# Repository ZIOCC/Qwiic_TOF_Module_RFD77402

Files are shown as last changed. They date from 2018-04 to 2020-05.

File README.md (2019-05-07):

# Qwiic TOF Module (RFD77402)

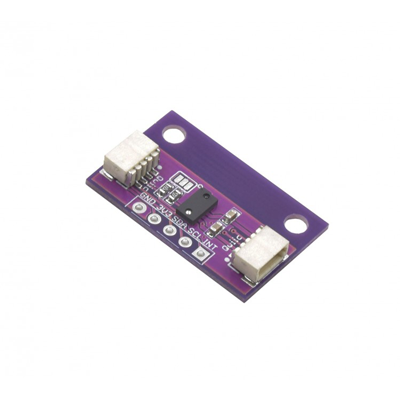
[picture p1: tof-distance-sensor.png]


> This product can be available for purchase [here](https://www.smart-prototyping.com/Zio-TOF-Distance-Sensor-RFD77402.html).

#### Description

In the words of a team member, “kind of dope AF”, this Zio ToF Distance Sensor measures distance faster than the Flash can cover it. If you don’t believe us, you can ask him.

This little board features an RFD77402 time-of-flight rangefinding IC, measuring up to 2m in distance. The sensor uses a vertical-cavity surface-emitting laser (or VCSEL), and measures the time it takes for photons to make the round-trip to the laser’s target, and back to the built-in detector. The laser emitter is class 1, therefore safe for most all applications.

We’ve outfitted the board with mounting holes on wing tabs that can be snapped off to create an even smaller board if you don’t need them. Two Qwiic connectors occupy either side of the breakout board so you can quickly and easily daisy-chain it with other modules. It also includes a standard-pitch header for use with projects that aren’t Qwiic-based.

Apply this sensor in a wide-range of applications such as in robotics for obstacle detection and avoidance, 1D gesture recognition, hand detection, volume or height control, relative position of linear actuators, or for user proximity detection for IoT devices.

Check out this Brick Breaker game that we hacked together using a similar sensor.

#### Specification

* Light Source: VCSEL / 850 nm
* Field of Illumination: 29-degree @ 1/e2
* Field of View: 55-degree @ 1/e2
* Measurement Range: 100-2000mm
* Refresh Rate: 10Hz
* Precision: ±10%
* Laser Eye Safety: Class 1
* Current Consumption: 7-15mA
* IC: RFD77402
* I2C address: 0x4C
* Dimensions: 16.5x 26.3mm (with mounting bar). 26.3x10.5mm (without mounting bar)
* Weight: 1.2g

#### Links

* [RFD77402 Datasheet](https://www.smart-prototyping.com/image/data/NOA-RnD/101891%20TOF/RFD77402DatasheetRev1-8.pdf)
* [SparkFun RFD77402  Library](https://github.com/sparkfun/SparkFun_RFD77402_Arduino_Library)
* [Eagle files](https://github.com/ZIOCC/Qwiic_TOF_Module_RFD77402)

> ###### About Zio
> Zio is a new line of open sourced, compact, and grid layout boards, fully integrated for Arduino and Qwiic ecosystem. Designed ideally for wearables, robotics, small-space limitations or other on the go projects. Check out other awesome Zio products [here](https://www.smart-prototyping.com/Zio).

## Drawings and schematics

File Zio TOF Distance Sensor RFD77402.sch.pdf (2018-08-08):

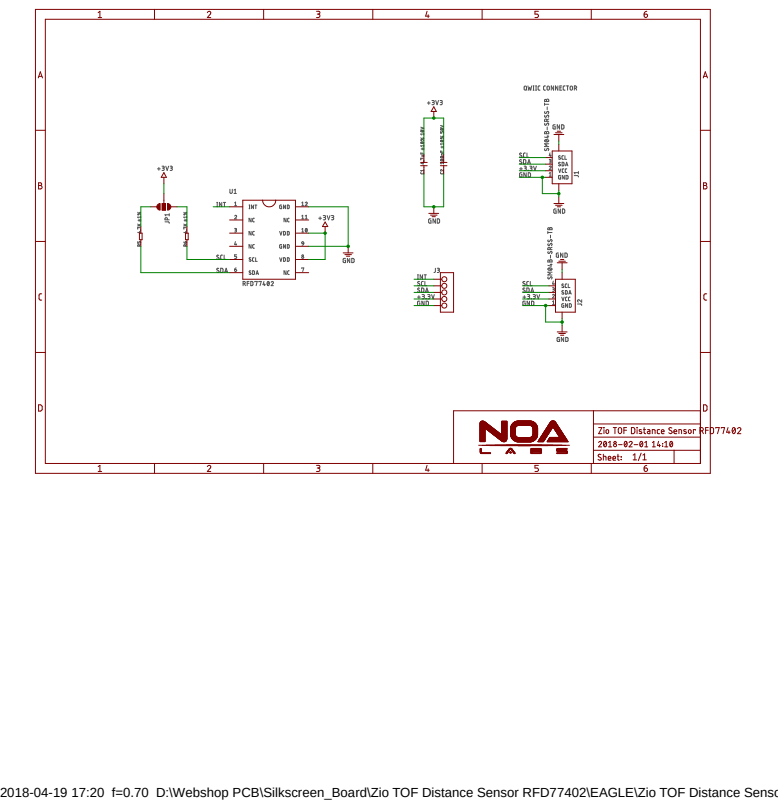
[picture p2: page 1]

2018-04-19 17:20 f=0.70 D:\Webshop PCB\Silkscreen_Board\Zio TOF Distance Sensor RFD77402\EAGLE\Zio TOF Distance Sensor RFD77402.sch (Sheet: 1/1)

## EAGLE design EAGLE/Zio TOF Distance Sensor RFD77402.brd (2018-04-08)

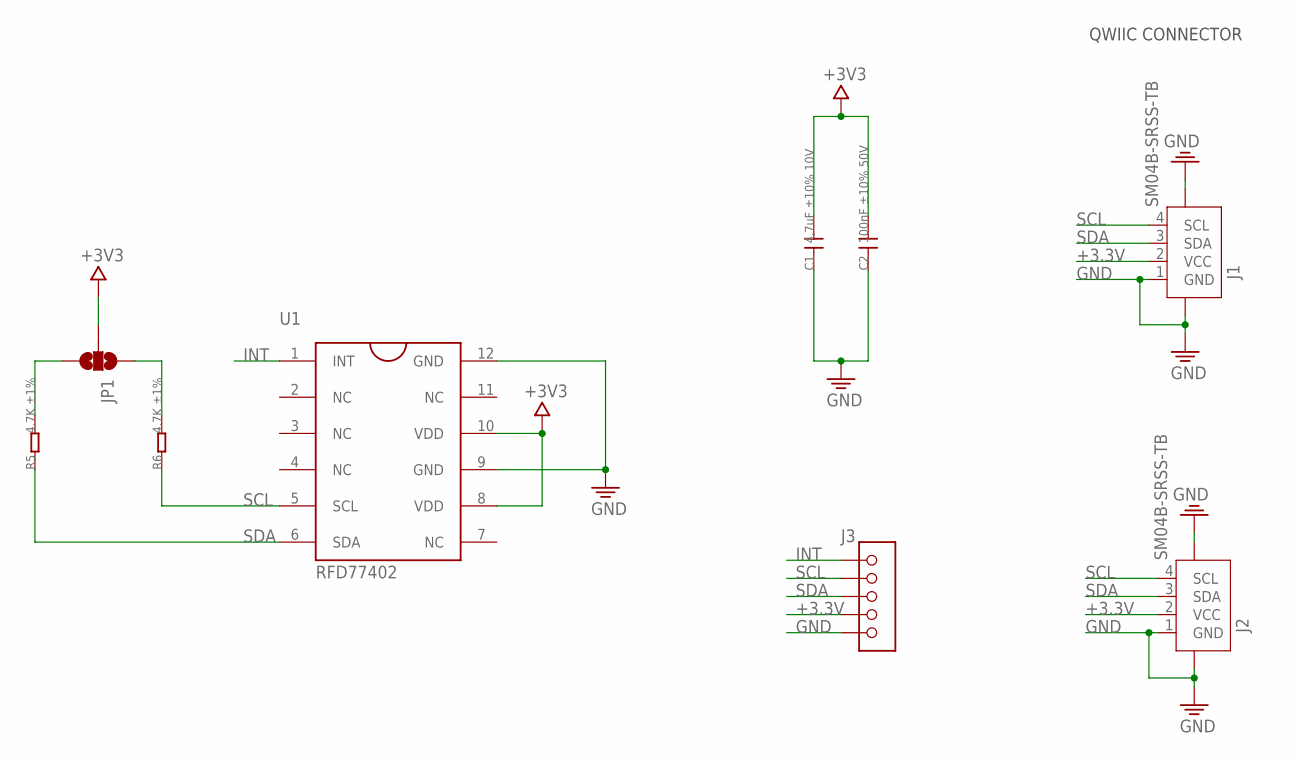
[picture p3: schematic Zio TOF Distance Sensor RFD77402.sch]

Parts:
C1: 4.7uF ±10% 10V; 0603
C2: 100nF ±10% 50V; 0603
J1, J2: SM04B-SRSS-TB; JST-SH-4P
J3: HEADER-5P-2.54; 5P-2.54
JP1: JUMPER-SMT_3_2-NC_PASTE_NOCREM; SMT-JUMPER_3_2-NC_PASTE_SILK_NOCREM
R5, R6: 4.7K ±1%; 0603
U1: RFD77402

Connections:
+3.3V: C1.2, C2.2, J1.2 (VCC), J2.2 (VCC), J3.4, JP1.2, U1.8 (VDD), U1.10 (VDD)
GND: C1.1, C2.1, J1.1 (GND), J1.NC1 (5), J1.NC2 (6), J2.1 (GND), J2.NC1 (5), J2.NC2 (6), J3.5, U1.9 (GND), U1.12 (GND)
INT: J3.1, U1.1 (INT)
unnamed: JP1.3, R5.2
unnamed: JP1.1, R6.2
SCL: J1.4 (SCL), J2.4 (SCL), J3.2, R6.1, U1.5 (SCL)
SDA: J1.3 (SDA), J2.3 (SDA), J3.3, R5.1, U1.6 (SDA)

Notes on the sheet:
QWIIC CONNECTOR

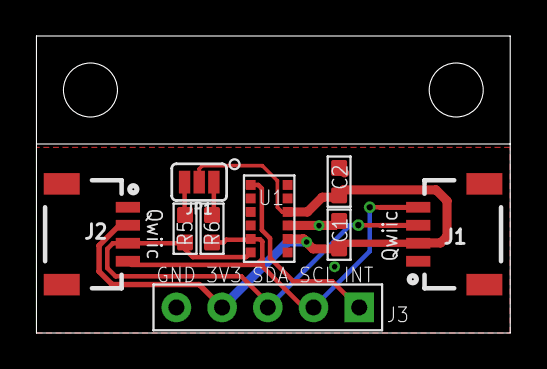
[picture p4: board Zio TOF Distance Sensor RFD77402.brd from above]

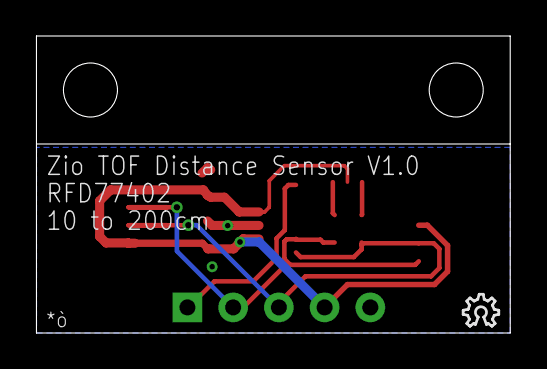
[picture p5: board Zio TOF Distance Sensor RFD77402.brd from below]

Board: 2 copper layers, 26.3 x 16.5 mm, 11 parts (2 on the bottom side), 7 nets.

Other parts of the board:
E$3: 6MM
LOGO1: LOGO-OSHW-6MILX0070-NT; OSHW_6X70_NOTEXT

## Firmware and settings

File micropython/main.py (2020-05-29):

"""
Demo code for RFD77402 TOF sensor
Auther: Alex Chu
Website: www.smart-prototyping.com
Email: shop@smart-prototyping.com
TOF RFD77402 product link: https://www.smart-prototyping.com/Zio-TOF-Distance-Sensor-RFD77402.html
Display product link: https://www.smart-prototyping.com/Zio-OLED-Display-0-91-in-128-32-Qwiic.html
Library: https://github.com/ZIOCC/Qwiic_TOF_Module_RFD77402/tree/master/micropython
"""

from machine import Pin,I2C
import rfd77402
from ssd1306 import SSD1306_I2C

i2c = I2C(sda=Pin("Y10"), scl=Pin("Y9"))
oled = SSD1306_I2C(128, 32, i2c, addr=0x3c)
tof = rfd77402.RFD77402(addr=0x4C,i2c=i2c)

pyb.delay(100)
tof.begin()

while True:
    tof.takeMeasurement()
    t = tof.getDistance()
    oled.fill(0)
    oled.text("Distance is:", 0, 0)
    oled.text(str(t) + " mm", 0, 20)
    oled.show()
    pyb.delay(100)

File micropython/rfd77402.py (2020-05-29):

'''
Auther: Alex Chu
Website: www.smart-prototyping.com
Email: shop@smart-prototyping.com
product link: https://www.smart-prototyping.com/Zio-TOF-Distance-Sensor-RFD77402.html
RFD77402 datasheet: https://www.smart-prototyping.com/image/data/NOA-RnD/101891%20TOF/RFD77402DatasheetRev1-8.pdf
#reference: https://github.com/sparkfun/SparkFun_RFD77402_Arduino_Library/tree/master/src
'''

from machine import Pin,I2C
import pyb

RFD77402_ICSR = 0x00
RFD77402_INTERRUPTS = 0x02
RFD77402_COMMAND = 0x04
RFD77402_DEVICE_STATUS = 0x06
RFD77402_RESULT = 0x08
RFD77402_RESULT_CONFIDENCE= 0x0A
RFD77402_CONFIGURE_A = 0x0C
RFD77402_CONFIGURE_B = 0x0E
RFD77402_HOST_TO_MCPU_MAILBOX = 0x10
RFD77402_MCPU_TO_HOST_MAILBOX = 0x12
RFD77402_CONFIGURE_PMU = 0x14
RFD77402_CONFIGURE_I2C = 0x1C
RFD77402_CONFIGURE_HW_0 = 0x20
RFD77402_CONFIGURE_HW_1 = 0x22
RFD77402_CONFIGURE_HW_2 = 0x24
RFD77402_CONFIGURE_HW_3 = 0x26
RFD77402_MOD_CHIP_ID = 0x28

RFD77402_MODE_MEASUREMENT = 0x01
RFD77402_MODE_STANDBY = 0x10
RFD77402_MODE_OFF = 0x11
RFD77402_MODE_ON = 0x12

CODE_VALID_DATA = 0x00
CODE_FAILED_PIXELS = 0x01
CODE_FAILED_SIGNAL = 0x02
CODE_FAILED_SATURATED = 0x03
CODE_FAILED_NOT_NEW = 0x04
CODE_FAILED_TIMEOUT = 0x05

I2C_SPEED_STANDARD = 100000
I2C_SPEED_FAST = 400000

INT_CLR_REG = 1 # tells which register read clears the interrupt (Default: 1, Result Register)
INT_CLR = 0 << 1 # tells whether or not to clear when register is read (Default: 0, cleared upon register read)
INT_PIN_TYPE = 1 << 2 # tells whether int is push-pull or open drain (Default: 1, push-pull)
INT_LOHI = 0 << 3 # tells whether the interrupt is active low or high (Default: 0, active low)

# Setting any of the following bits to 1 enables an interrupt when that event occurs
INTSRC_DATA = 1      # Interrupt fires with newly available data
INTSRC_M2H = 0 << 1  # Interrupt fires with newly available data in M2H mailbox register
INTSRC_H2M = 0 << 2  # Interrupt fires when H2M register is read
INTSRC_RST = 0 << 3  # Interrupt fires when HW reset occurs


class RFD77402:

    def __init__(self,addr,i2c):
        self.addr = 0x4C
        self.i2c = i2c
        self.distance = 0
        self.validPixels = 0
        self.confidenceValue = 0
        self.calibrationData =[]
        self.cmd_1_byte =bytearray(1)
        self.cmd_2_byte = bytearray(2)

    def begin(self):
        if self.getChipID() < 0xAD00:
            return False
        # Deivce power on flow, from datasheet page 29
        if self.goToStandbyMode() == False:
            return False
        # Drive INT_PAD high
        setting = self.i2c.readfrom_mem(self.addr, RFD77402_ICSR, 1)
        # clears writable bits
        setting_int = setting[0] & 0b11110000
        # change bits to enable interrupt
        setting_int |= INT_CLR_REG | INT_CLR | INT_PIN_TYPE | INT_LOHI
        self.cmd_1_byte[0] = setting_int
        print(self.cmd_1_byte)
        self.i2c.writeto_mem(self.addr, RFD77402_ICSR, self.cmd_1_byte)
        setting = self.i2c.readfrom_mem(self.addr, RFD77402_INTERRUPTS, 1)
        # Clears bits
        setting_int = setting[0] & 0b00000000
        # setting = 0b00000000
        setting_int |= INTSRC_DATA | INTSRC_M2H | INTSRC_H2M | INTSRC_RST
        self.cmd_1_byte[0] = setting_int
        # setting |= INTSRC_DATA | INTSRC_M2H | INTSRC_H2M | INTSRC_RST  # Enables interrupt when data is ready
        self.i2c.writeto_mem(self.addr, RFD77402_INTERRUPTS, self.cmd_1_byte) # 1 byte
        # Configure I2C Interface,
        # //0b.0110.0101 = 0x65 Address increment, auto increment, host debug, MCPU debug, 2.1.3 setting
        self.i2c.writeto_mem(self.addr, RFD77402_CONFIGURE_I2C, b'\x65')
        # //0b.0000.0101.0000.0000 //Patch_code_id_en, Patch_mem_en
        self.i2c.writeto_mem(self.addr, RFD77402_CONFIGURE_PMU, b'\x00\x05')  # 0x0500
        if self.goToOffMode() == False:
            return False
        # set initialization - Magic from datasheet. Write 0x0600 to 0x14 location
        self.i2c.writeto_mem(self.addr, RFD77402_CONFIGURE_PMU, b'\x00\x06') # 0x0600
        if self.goToOnMode() == False:
            return False
        # set peak and threshold 0xe100
        self.i2c.writeto_mem(self.addr, RFD77402_CONFIGURE_A, b'\x00\xe1')
        self.i2c.writeto_mem(self.addr, RFD77402_CONFIGURE_B, b'\xff\x10') # Set valid pixel. Set MSP430 default config. cmd: 0x10FF
        self.i2c.writeto_mem(self.addr, RFD77402_CONFIGURE_HW_0, b'\xd0\x07') # Set saturation threshold = 2,000.   cmd:0x07D0
        self.i2c.writeto_mem(self.addr, RFD77402_CONFIGURE_HW_1, b'\x08\x50') # Frequecy = 5. Low level threshold = 8, cmd: 0x5008
        self.i2c.writeto_mem(self.addr, RFD77402_CONFIGURE_HW_2, b'\x41\xa0') # cmd: 0xA041. Integration time = 10 * (6500-20)/15)+20 = 4.340ms. Plus reserved magic.
        self.i2c.writeto_mem(self.addr, RFD77402_CONFIGURE_HW_3, b'\xd4\x45') # cmd: 0x45D4. Enable harmonic cancellation. Enable auto adjust of integration time. Plus reserved magic.
        # Error - MCPU never went to standby
        if self.goToStandbyMode() == False:
            return False
        # Set initialization - Magic from datasheet. Write 0x05 to 0x15 location.
        self.i2c.writeto_mem(self.addr, RFD77402_CONFIGURE_PMU, b'\x00\x05')
        if self.goToOffMode() == False:
            return False
        # Set initialization - Magic from datasheet. Write 0x06 to 0x15 location.
        self.i2c.writeto_mem(self.addr, RFD77402_CONFIGURE_PMU, b'\x00\x06')
        if self.goToOnMode() == False:
            return False
        return True

    # Single Measure Flow, from datasheet page 30
    def takeMeasurement(self):
        if self.goToMeasurementMode() == False:
            return CODE_FAILED_TIMEOUT
        resultRegister = self.i2c.readfrom_mem(self.addr, RFD77402_RESULT,2)
        resultRegister_int = (resultRegister[1]<<8) | resultRegister[0]
        if resultRegister_int & 0x7FFF:
            errorCode = (resultRegister[1] >> 5) & 0x03
            if errorCode == 0:
                self.distance = ((resultRegister[1] & 0x1F) << 8) | resultRegister[0] # Distance is good. Read it.
                self.distance = self.distance >> 2
                confidenceRegister = self.i2c.readfrom_mem(self.addr, RFD77402_RESULT_CONFIDENCE, 2)
                confidenceRegister_int = (confidenceRegister[1] << 8) | confidenceRegister[0]
                self.validPixels = confidenceRegister_int & 0x0F
                self.confidenceValue = (confidenceRegister_int >> 4) & 0x07FF
            else:
                return errorCode
        else:
            return CODE_FAILED_NOT_NEW

    def getDistance(self):
        return self.distance

    def getValidPixels(self):
        return self.validPixels

    def getConfidenceValue(self):
        return self.confidenceValue

    def getMode(self):
        return (self.i2c.readfrom_mem(self.addr, RFD77402_COMMAND,1)[0] & 0x3F)
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
